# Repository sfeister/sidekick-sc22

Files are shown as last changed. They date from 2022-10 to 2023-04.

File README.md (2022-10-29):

# sidekick-sc22

Physical demonstration of closed loop control systems for machine learning. Supercomputing Conference 2022.

Collaborative work between California State University Channel Islands and Lawrence Livermore National Laboratory.

Based directly on the first Sidekick EPICS system we built: https://github.com/sfeister/sidekick-epics

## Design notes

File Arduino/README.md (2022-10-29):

# Arduino

Each Raspberry Pi has exactly one or more Arduinos attached. The Raspberry Pi sends commands and receives data from the Arduino(s) via USB.

Each .ino sketch in this folder is compiled and uploaded to an Arduino Nano or Arduino Uno. Then, the Arduino is plugged into a Raspberry Pi via USB.

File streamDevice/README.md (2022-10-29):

# streamDevice

Each Raspberry Pi has one or more Arduinos attached. The Raspberry Pi sends commands and receives data from the Arduino(s) via USB.

USB serial communication is translated to and from EPICS process variables via an EPICS module called [StreamDevice](
http://epics.web.psi.ch/software/streamdevice/).

"streamDevice" settings files for each EPICS input/output controller (on the Raspberry Pi) are contained in this folder.

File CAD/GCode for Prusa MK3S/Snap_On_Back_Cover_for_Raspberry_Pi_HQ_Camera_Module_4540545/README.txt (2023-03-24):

Snap On Back Cover for Raspberry Pi HQ Camera Module by mikelane76 on Thingiverse: https://www.thingiverse.com/thing:4540545

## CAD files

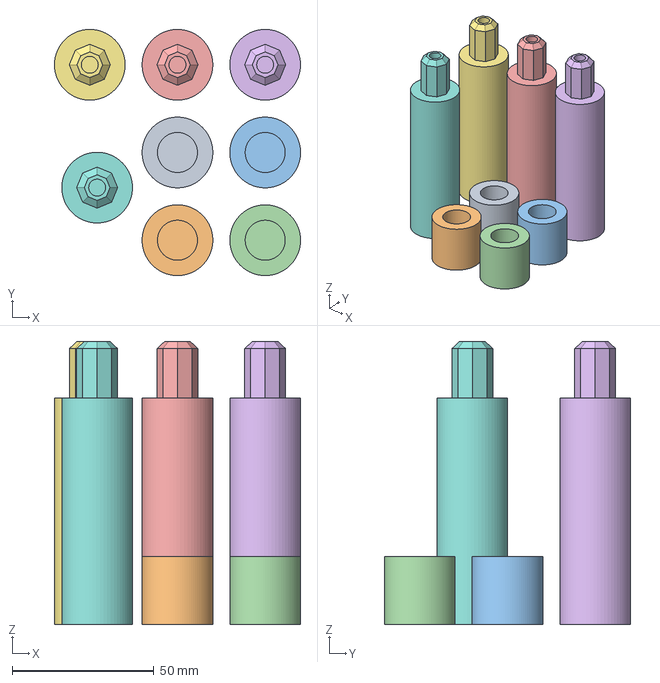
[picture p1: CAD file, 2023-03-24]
CAD/PrusaSlicer/Acrylic Posts and Caps (print in accent color).3mf
87.0 x 87.0 x 100.0 mm
Acrylic Support Post Caps.stl x 4
Acrylic Support Post.stl x 4

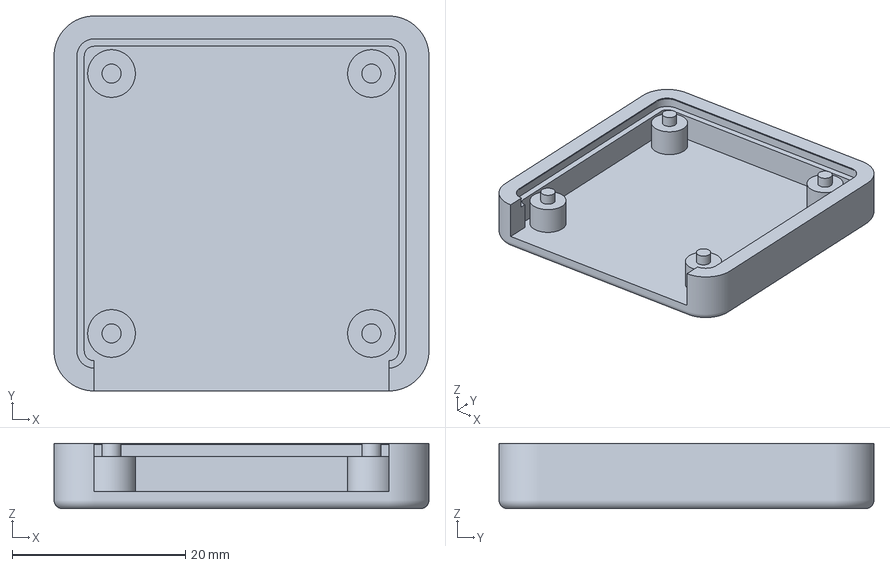
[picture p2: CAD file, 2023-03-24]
CAD/PrusaSlicer/Snap_On_Back_Cover_for_Raspberry_Pi_HQ_Camera_Module_4540545/RPi_HQ_Camera_Back (print in accent color).3mf
43.3 x 43.3 x 7.55 mm

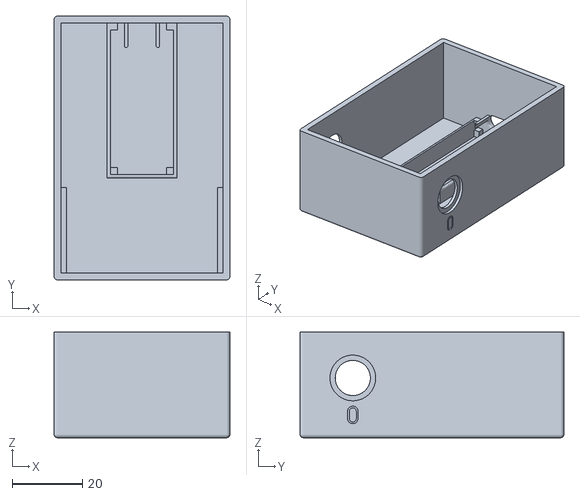
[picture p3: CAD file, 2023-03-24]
CAD/STL/Pulse Generator Enclosure.stl
50.0 x 75.0 x 30.0

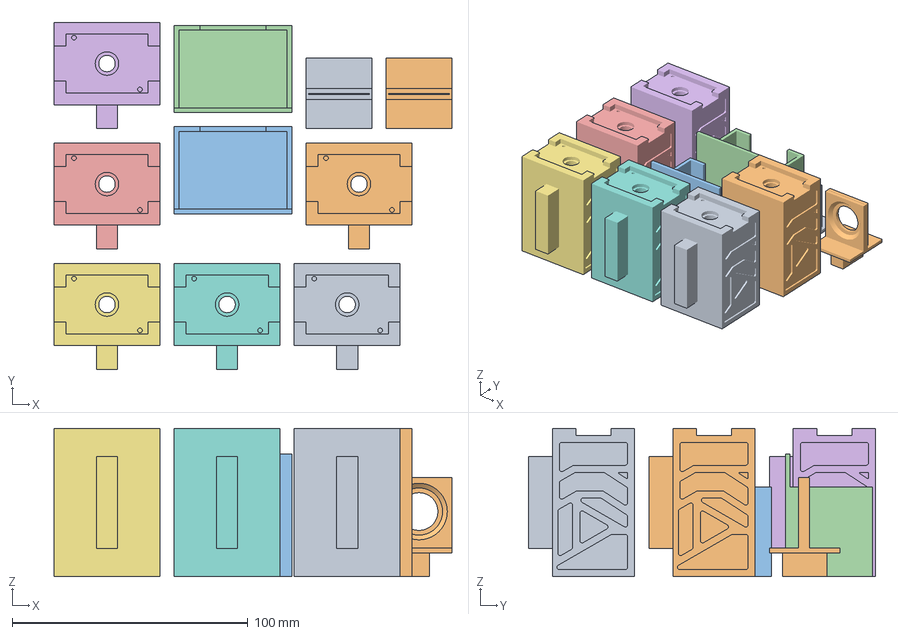
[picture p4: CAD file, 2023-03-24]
CAD/PrusaSlicer/Targets and Hats and Flashing LEDs (print in black).3mf
169.0 x 147.5 x 63.0 mm
Target With Slot for Deli-Paper.stl x 2
Target Hat.stl x 2
Flashing NeoPixel LED Enclosure.stl x 6

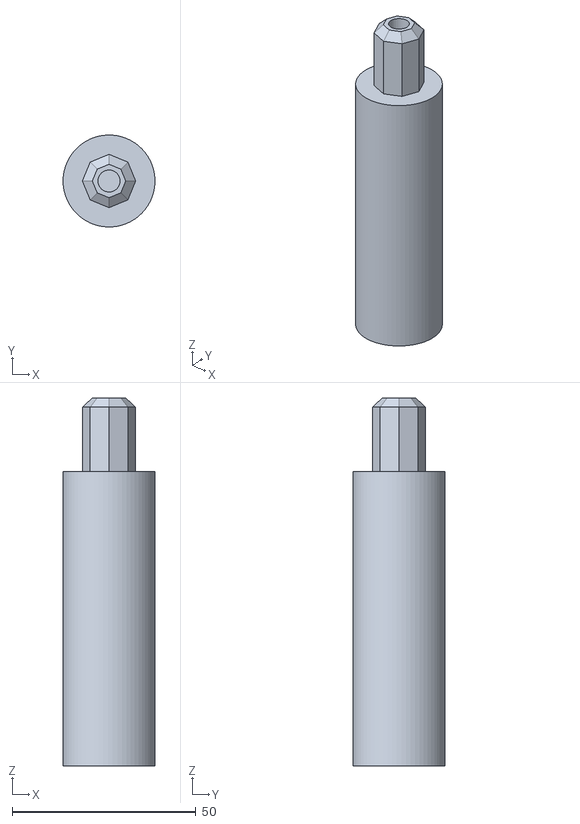
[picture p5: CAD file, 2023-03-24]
CAD/STL/Acrylic Support Post.stl
25.0 x 25.0 x 100.0

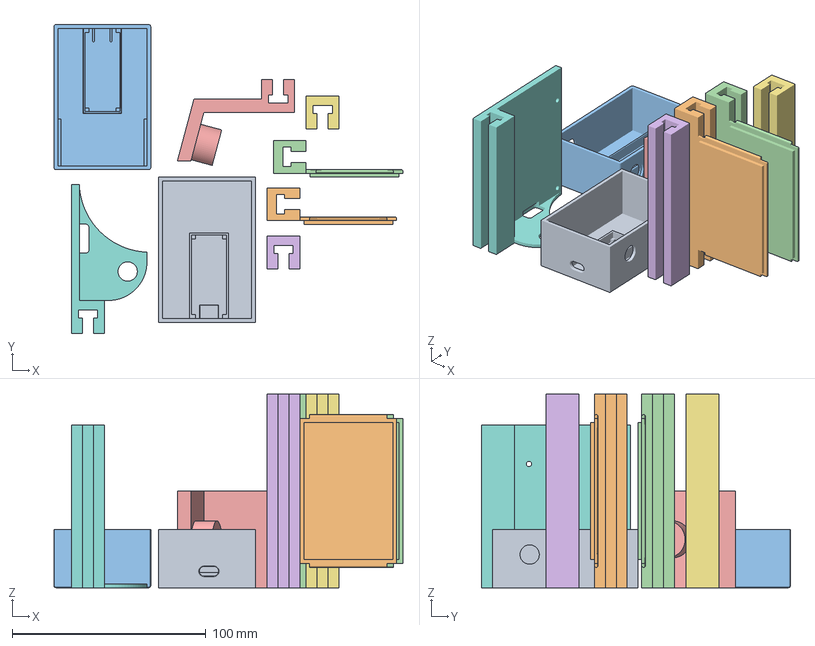
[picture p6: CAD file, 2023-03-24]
CAD/PrusaSlicer/Boxes Lids Clips and Camera Mounts (print in gray).3mf
180.4 x 159.6 x 100.0 mm
Flashing NeoPixel LED Driver Enclosure.stl
Pulse Generator Clip-On Lid.stl x 2
Pulse Generator Enclosure.stl
PiHQ Camera Clip-On Mount.stl
Sidelight LED Strip Clip-On.stl x 2
Raspberry Pi 4 Clip-On Base with BNC.stl

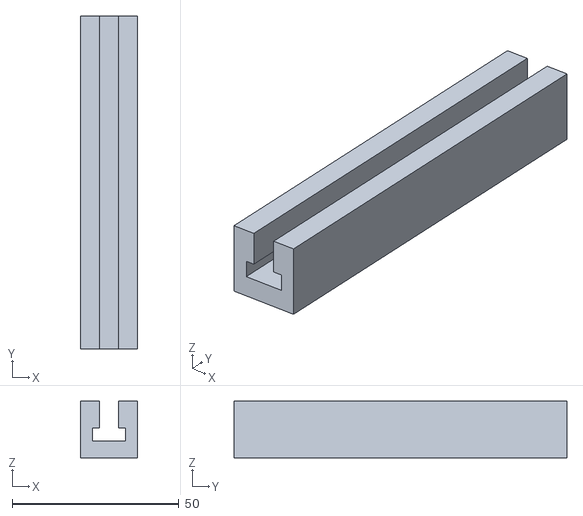
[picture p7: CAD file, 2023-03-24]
CAD/STL/Sidelight LED Strip Clip-On.stl
17.0 x 100.0 x 17.0

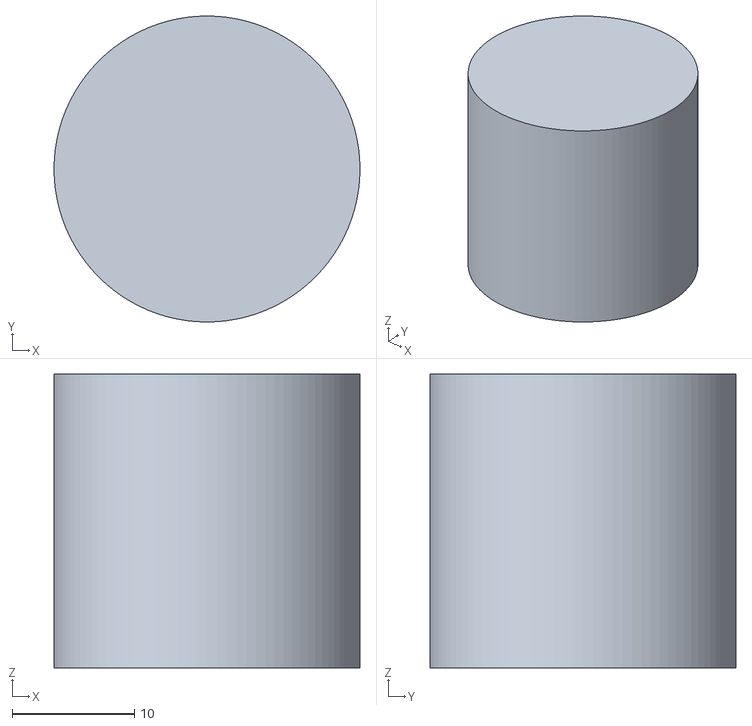
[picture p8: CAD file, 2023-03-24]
CAD/STL/Acrylic Support Post Caps.stl
25.0 x 25.0 x 24.0

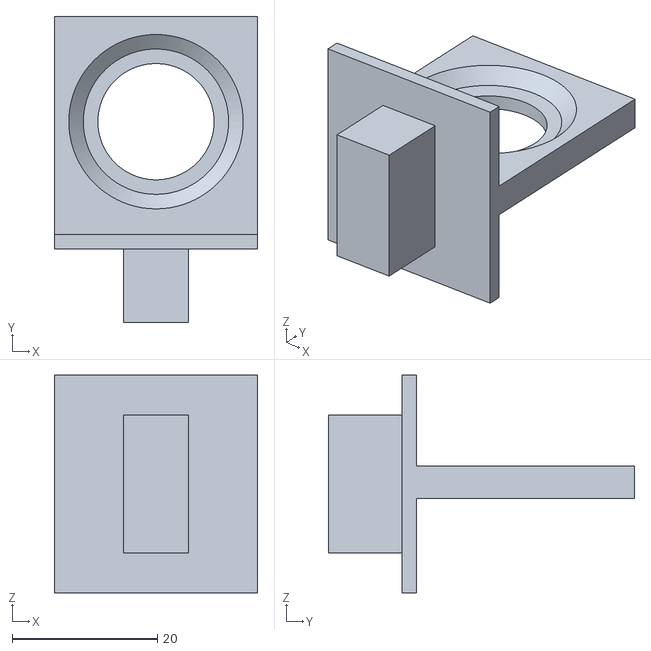
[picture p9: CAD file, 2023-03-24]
CAD/STL/Target With Slot for Deli-Paper.stl
28.0 x 42.2 x 30.0

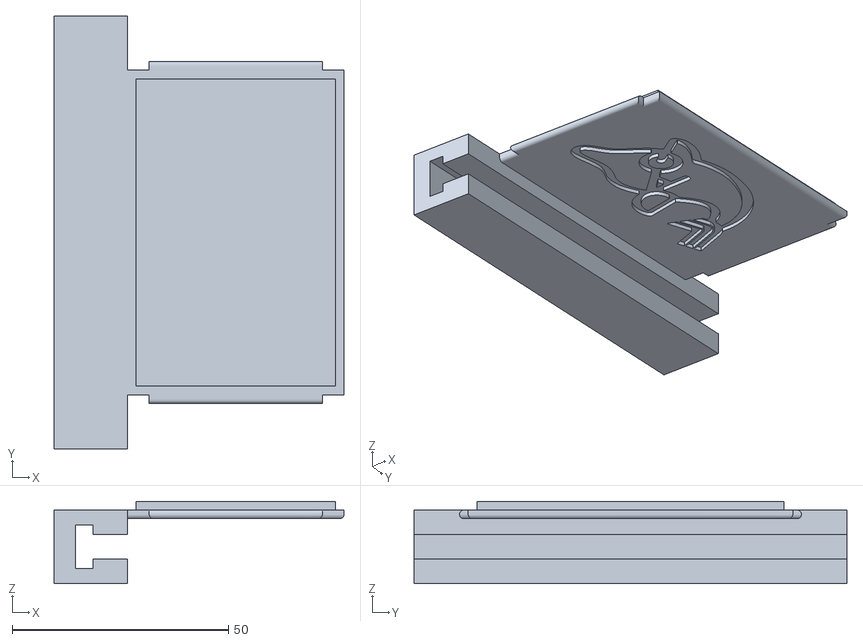
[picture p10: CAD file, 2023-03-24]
CAD/STL/Pulse Generator Clip-On Lid.stl
67.0 x 100.0 x 19.0

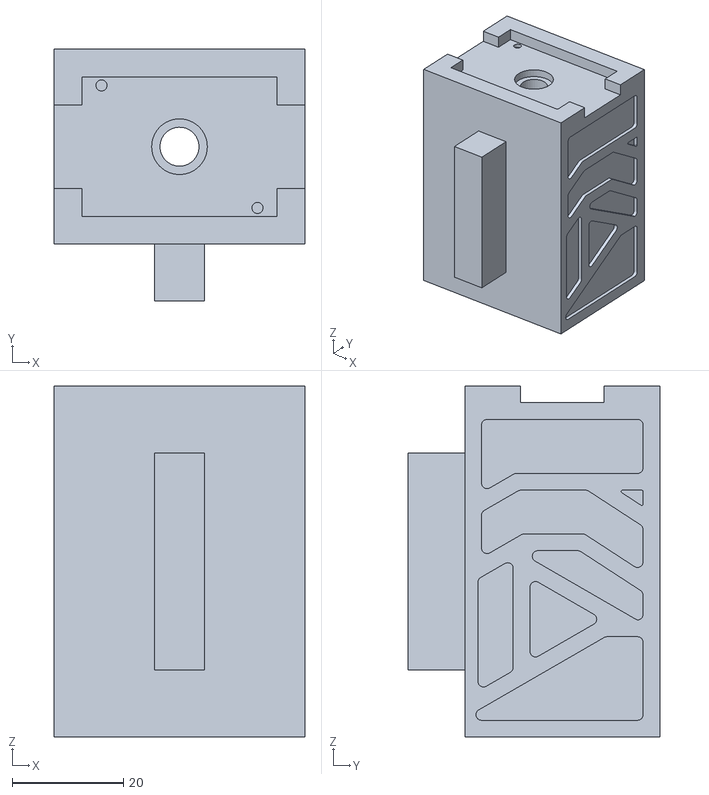
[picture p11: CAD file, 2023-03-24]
CAD/STL/Flashing NeoPixel LED Enclosure.stl
45.0 x 45.2 x 63.0

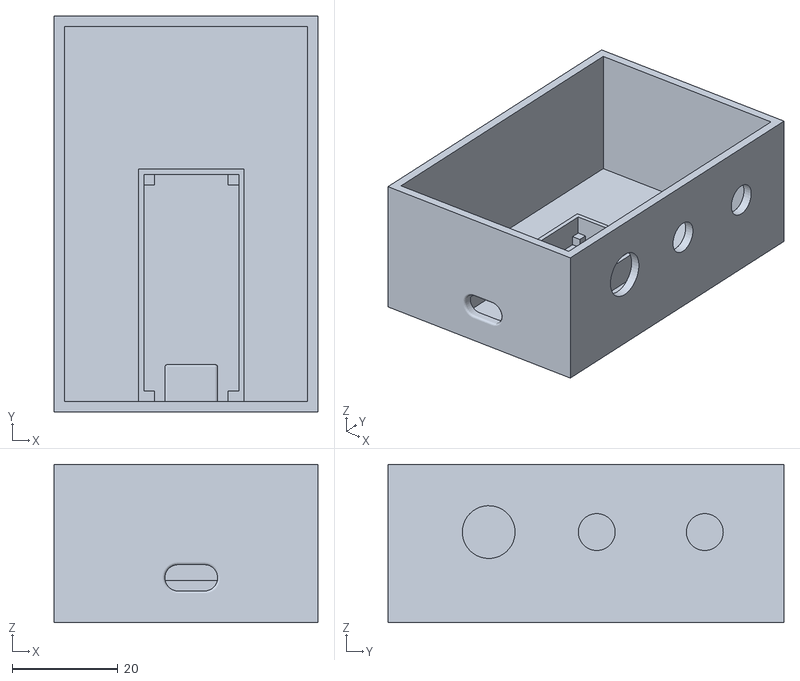
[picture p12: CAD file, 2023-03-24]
CAD/STL/Flashing NeoPixel LED Driver Enclosure.stl
50.0 x 75.0 x 30.0

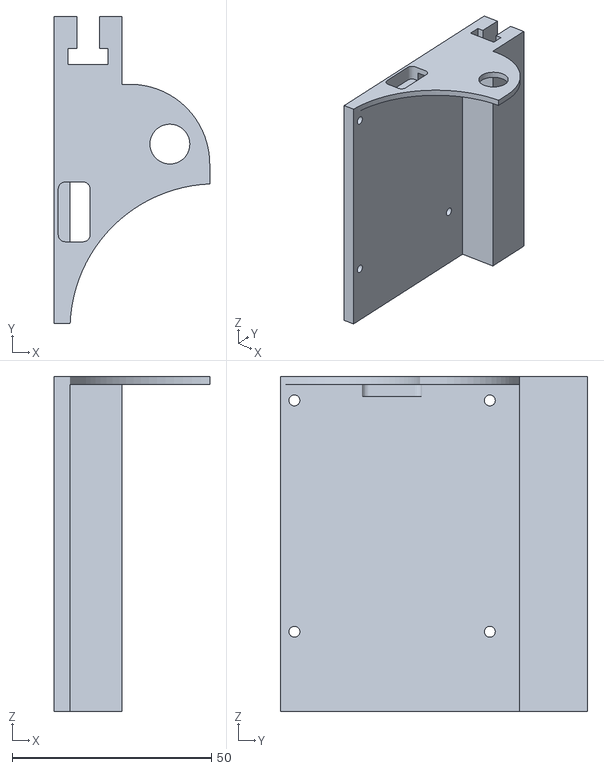
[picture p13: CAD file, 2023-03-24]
CAD/STL/Raspberry Pi 4 Clip-On Base with BNC.stl
39.0 x 77.0 x 84.0

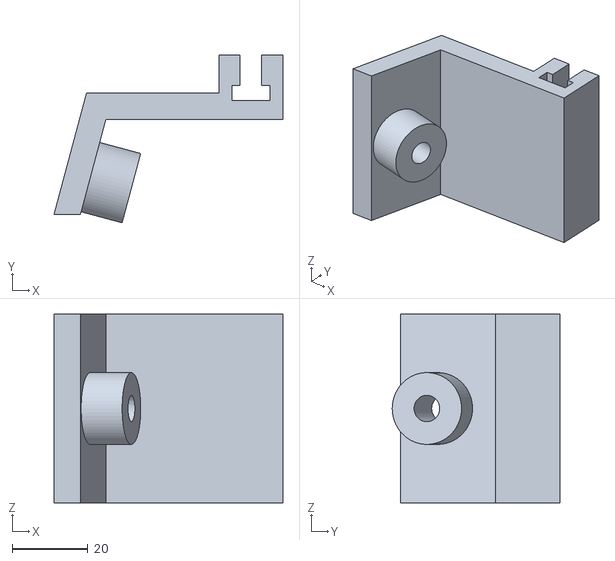
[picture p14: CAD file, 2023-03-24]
CAD/STL/PiHQ Camera Clip-On Mount.stl
60.6 x 44.4 x 50.0

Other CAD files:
CAD/STL/Snap_On_Back_Cover_for_Raspberry_Pi_HQ_Camera_Module_4540545/RPi_HQ_Camera_Back.stl
CAD/STL/Target Hat.stl

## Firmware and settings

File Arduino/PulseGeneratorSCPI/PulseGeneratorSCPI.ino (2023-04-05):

/*
PulseGeneratorSCPI.ino

Generates 3.3 V TTL square pulses at a specified repetition rate.

Important Notes:
 * Creates eight independently delayed TTL pulses. Each channel's delay time is specified in milliseconds relative to TRIGOUT.
 * Each TTL pulse is emitted as HIGH (3.3 V) with a 3 millisecond duration, after which is goes back to its LOW state (0 V).
 * The overall repetition rate of the system can be adjusted up to about 20 Hz (depending on other time delay choices).
 * Typical precision of the requested delay times (on an Arduino Uno) should be a millisecond. Timing jitters around about a millisecond.
 * "Time-zero" trigger output can be monitored on Arduino Pin 3.
 * Up to eight channels (CH0 - CH7) of controlled TTL pulse outputs can be wired to Arduino Pins 4, 5, 6, 7, 8, 9, 10, 11.

Serial Commands (lower-case portions are optional):
  *IDN?                 Responds with a device identification string.
  DELay:CHannelN VAL    Sets Channel N (0-7) output delay to VAL (unsigned long integer, in milliseconds).
  DELay:CHannelN?       Responds with output delay (unsigned long integer, in milliseconds) of Channel N (0-7).
  REPrate VAL           Sets system-wide repetition-rate to VAL (double, in Hz).
  REPrate?              Responds with the system-wide repetition-rate (double, in Hz).

References:
 1. Following timer instructions at: https://github.com/contrem/arduino-timer
 2. Following Vrekrer SCPI Parser examples, e.g. at https://github.com/Vrekrer/Vrekrer_scpi_parser/blob/master/examples/Numeric_suffixes/Numeric_suffixes.ino

Created by Scott Feister, Emiko Ito, and Keily Valdez-Sereno of California State University Channel Islands in Fall 2021. Updated for millisecond delays in March 2023.
*/

#include "Arduino.h"
#include <math.h>
#include <arduino-timer.h>
#include "Vrekrer_scpi_parser.h"

#define TRIGOUT 3 // The "zero delay" TRIGOUT TTL pulse is output on Arduino Pin 3
#define NCHAN 8 // Total number independently delayed output TTL pulse output channels
#define CH0 4 // Channel 0 TTL pulse is output on Arduino Pin 4
#define CH1 5 // Channel 1 TTL pulse is output on Arduino Pin 5
#define CH2 6 // Channel 2 TTL pulse is output on Arduino Pin 6
#define CH3 7 // Channel 3 TTL pulse is output on Arduino Pin 7
#define CH4 8 // Channel 4 TTL pulse is output on Arduino Pin 8
#define CH5 9 // Channel 5 TTL pulse is output on Arduino Pin 9
#define CH6 10 // Channel 5 TTL pulse is output on Arduino Pin 10
#define CH7 11 // Channel 5 TTL pulse is output on Arduino Pin 11

/* Serial communication initialization */
SCPI_Parser my_instrument;

/* Timing initialization */
Timer<10, millis, int> timer1; // TTL pulse timer with 10 task slots, millisecond resolution, and handler argument type int
Timer<1, millis> timer2; // rep-rate timer with 1 task slot, millisecond resolution, and void-type handler

int chanPins[NCHAN]; // Pins for each channel
unsigned long delays[NCHAN]; // Millisecond delay times for each channel

int pulseTime = 3; // TTL pulse duration in milliseconds
double repRate = 1.0; // pulse repetition-rate in Hz
unsigned long t0;

/* Timing functions */
bool TTLStop(int chanPin) {
    // Bring this pulse output back to LOW
    digitalWrite(chanPin, LOW);
    return false; // to repeat the action - false to stop
}

bool TTLStart(int chanPin) {
    // Bring this channel output to HIGH
    digitalWrite(chanPin, HIGH);
    timer1.in(pulseTime, TTLStop, chanPin); // Start a timer to bring this signal back to LOW
    return false; // to repeat the action - false to stop
}

bool trigStart(void *argument){
    if (timer1.size() < 1) { // Only start a new set of triggers if the old set is completed
      t0 = millis() + 2; // Set "time zero" two milliseconds into the future to get everything set up first

      // Schedule the "TRIGOUT" / t0 pulse
      timer1.at(t0, TTLStart, TRIGOUT);
      
      // Schedule the channel pulses
      for(int i = 0; i < NCHAN; ++i)
      {
          timer1.at(t0 + delays[i], TTLStart, chanPins[i]); // Start a timer for this channel
      }
    }
    return true; // repeat at the next interval of the timer
}

void updateRepRate(double repRateHz){
  // Sets the repetition-rate, with value in Hz
  timer2.cancel();
  int repTime = round(1000 / repRateHz);
  timer2.every(repTime, trigStart); // Start a timer for this channel
  repRate = repRateHz; // Update the global variable "repRate"
}

/* Serial communication functions */
void identify(SCPI_C commands, SCPI_P parameters, Stream& interface) {
  interface.println(F("DolphinDAQ,SC22 PulseGen,#00,20230405"));
}


void getRepRate(SCPI_C commands, SCPI_P parameters, Stream& interface) {
  interface.println(repRate);
}

void setRepRate(SCPI_C commands, SCPI_P parameters, Stream& interface) {
  String first_parameter = String(parameters.First());
  updateRepRate(first_parameter.toDouble());
}

void getDelay(SCPI_C commands, SCPI_P parameters, Stream& interface) {
  // This function is modified from the Vrekrer examples: https://github.com/Vrekrer/Vrekrer_scpi_parser/blob/master/examples/Numeric_suffixes/Numeric_suffixes.ino
  
  //Get the numeric suffix/index (if any) from the commands
  String header = String(commands.Last());
  header.toUpperCase();
  int suffix = -1;
  sscanf(header.c_str(),"%*[CHANNEL]%u", &suffix);

  //If the suffix is valid, print the channel's value to the interface
  if ( (suffix >= 0) && (suffix < NCHAN) ) {
      interface.println(delays[suffix]);
  }
}

void setDelay(SCPI_C commands, SCPI_P parameters, Stream& interface) {
  // This function is modified from the Vrekrer examples: https://github.com/Vrekrer/Vrekrer_scpi_parser/blob/master/examples/Numeric_suffixes/Numeric_suffixes.ino
  
  //Get the numeric suffix/index (if any) from the commands
  String header = String(commands.Last());
  header.toUpperCase();
  int suffix = -1;
  sscanf(header.c_str(),"%*[CHANNEL]%u", &suffix);

  //If the suffix is valid,
  //use the first parameter (if valid) to set the channel delay
  String first_parameter = String(parameters.First());
  if ( (suffix >= 0) && (suffix < NCHAN) ) {
      delays[suffix] = first_parameter.toInt();
  }
}


void setup() {
  /* Serial communication setup */
  my_instrument.RegisterCommand(F("*IDN?"), &identify);
  my_instrument.RegisterCommand(F("REPrate?"), &getRepRate);
  my_instrument.RegisterCommand(F("REPrate"), &setRepRate);
  my_instrument.SetCommandTreeBase(F("DELay:"));
  my_instrument.RegisterCommand(F("CHannel#?"), &getDelay);
  my_instrument.RegisterCommand(F("CHannel#"), &setDelay);

  /* Timing setup */
  pinMode(TRIGOUT, OUTPUT); // Declare the TRIGOUT pin as a digital output
  pinMode(CH0, OUTPUT);
  pinMode(CH1, OUTPUT);
  pinMode(CH2, OUTPUT);
  pinMode(CH3, OUTPUT);  
  pinMode(CH4, OUTPUT);
  pinMode(CH5, OUTPUT);
  pinMode(CH6, OUTPUT);
  pinMode(CH7, OUTPUT);

  // Save pin numbers into the chanPins array
  chanPins[0] = CH0;
  chanPins[1] = CH1;
  chanPins[2] = CH2;
  chanPins[3] = CH3;
  chanPins[4] = CH4;
  chanPins[5] = CH5;
  chanPins[6] = CH6;
  chanPins[7] = CH7;
    
  // Save initial delay times (in milliseconds) into the delays array
  delays[0] = 0;
  delays[1] = 0;
  delays[2] = 0;
  delays[3] = 0;
  delays[4] = 0;
  delays[5] = 0;
  delays[6] = 0;
  delays[7] = 0;

  // Initialize the repetition rate
  updateRepRate(repRate); // Sets the repetition-rate, with value in Hz

  Serial.begin(115200);
}

void loop() {
  timer1.tick();
  timer2.tick();
  my_instrument.ProcessInput(Serial, "\r\n");
}

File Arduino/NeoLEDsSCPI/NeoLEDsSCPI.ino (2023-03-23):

/*
NeoLEDsSCPI.ino

When externally triggered, flashes six LEDs a single time. Each LED has its own flash duration and brightness.

Built directly off of LEDsSCPI.ino from the Sidekick system. Adapted for use with Adafruit Neopixels.

Important Notes:
 * LED flash begins abbout 5 milliseconds after the external trigger is received.
 * External trigger should be wired to Arduino Pin 2.
 * The Neopixel data pin should be wired to Arduino Pin 3.
 
Serial Commands (lower-case portions are optional):
  *IDN?                 Responds with a device identification string.
  DURation:LEDN VAL     Sets LED N (0-5) pulse duration to VAL (unsigned long integer, in milliseconds).
  DURation:LEDN?        Responds with LED N (0-5) pulse duration (unsigned long integer, in milliseconds).
  BRIGhtness:LEDN VAL   Sets LED N (0-5) brightness (PWM duty cycle) to VAL (integer, 0 to 255).
  BRIGhtness:LEDN?      Responds with LED N (0-5) brightness (PWM duty cycle)(integer, 0 to 255).
  RED:LEDN VAL          Sets LED N (0-5) to a Red VAL (0-1)
  RED:LEDN?             Responds with LED N (0-5) Red VAL (0-1)
  GREEN:LEDN VAL        Sets LED N (0-5) to a Green VAL (0-1)
  GREEN:LEDN?           Responds with LED N (0-5) Green VAL (0-1)
  BLUE:LEDN VAL         Sets LED N (0-5) to a Blue VAL (0-1)
  BLUE:LEDN?            Responds with LED N (0-5) Blue VAL (0-1)
 
References:
 1. Following timer instructions at: https://github.com/contrem/arduino-timer
 2. Following Vrekrer SCPI Parser examples, e.g. at https://github.com/Vrekrer/Vrekrer_scpi_parser/blob/master/examples/Numeric_suffixes/Numeric_suffixes.ino
 3. Attaching an interrupt pin for external triggering: https://www.arduino.cc/reference/en/language/functions/external-interrupts/attachinterrupt/ 

Created by Emiko Ito, Keily Valdez-Sereno, and Scott Feister of California State University Channel Islands between 2021 - 2022. Updated for miliseconds in March 2023.
*/

#include "Arduino.h" 
#include <arduino-timer.h>
#include "Vrekrer_scpi_parser.h"
#include <Adafruit_NeoPixel.h>
#ifdef __AVR__
  #include <avr/power.h>
#endif


#define EXTTRIG 2 // Note that this pin must be one of the Arduino pins capable of digital interrupt. See table at https://www.arduino.cc/reference/en/language/functions/external-interrupts/attachinterrupt/

#define NLED 6 // Total number of Neopixels in the strand, each with independent duration and brightness
#define LED0 3  //this is the data pin we will use for the neopixel strand

Adafruit_NeoPixel pixels(NLED, LED0, NEO_RGBW + NEO_KHZ800);


Timer<16, millis, int> timer1; // Timer with 16 task slots, millisecond resolution, and handler argument type int

//int LEDPins[NLED]; // Arduino pin numbers for each of the six LED outputs
int brights[NLED]; // Brightnesses for each of the six LEDs, when on
float red[NLED] =   {1, 0, 0, 1, 0, 0.75}; //red values for each pixel
float green[NLED] = {0, 1, 0, 0, 1, 0.25}; //green values for each pixel
float blue[NLED] =  {0, 0, 1, 1, 1, 0.50}; //blue values for each pixel
unsigned long durations[NLED]; // Pulse duration times, in milliseconds, for each of the six LEDs
unsigned long t0;
int trigCount = 0;

SCPI_Parser my_instrument;
int brightness = 0; // temp variable
float value = 0; // temp variable

/* LED control functions */
bool LEDStart(int LEDid) {
    // Turn on the LED of this index (0-5), with a specified brightness
    pixels.setPixelColor(LEDid, pixels.Color(brights[LEDid] * red[LEDid], brights[LEDid] * green[LEDid], brights[LEDid] * blue[LEDid]));
    pixels.show();
    return false; // to repeat the action - false to stop
}

bool LEDStop(int LEDid) {
    // Turn off the LED of this index (0-5)
    //just sets whatever pixel to all 0s so it's nothing
    pixels.setPixelColor(LEDid, pixels.Color(0, 0, 0, 0)); //set first pixel to color RED
    pixels.show();
    return false; // to repeat the action - false to stop
}

/* Timing functions */

// Interrupt service routine (ISR): Called upon external trigger.
// Starts one-time timers that govern the start/stop pulse of the LEDs
void myISR() {
    // Pulse the LEDs once, each with its own brightness and duration
    trigCount++;
    if (timer1.size() < 1) { // Only start a new set of LED pulses if the old set is completed
      t0 = millis() + 5; // Set "LED pulse time zero" to five milliseconds into the future to get everything set up first

      // Schedule the LED pulse starts and stops
      for(int i = 0; i < (NLED); ++i)
      {
          timer1.at(t0, LEDStart, i); // Set the start time for this LED
          timer1.at(t0 + durations[i], LEDStop, i); // Set the stop time for this LED (must be significantly after the start time)
      }
    }
    String triggerMsg = "STREAM " + String(trigCount) + ",";
    for (int i = 0; i < NLED; i++){
      triggerMsg = (triggerMsg + String(brights[i]) + ",");
    }    
    Serial.println(triggerMsg);
    
}

/* Serial communication functions */
void identify(SCPI_C commands, SCPI_P parameters, Stream& interface) {
  interface.println(F("DolphinDAQ,SC22 Neo-LEDs,#00,20230323"));
}

void getBrightness(SCPI_C commands, SCPI_P parameters, Stream& interface) {
  //Get the numeric suffix/index (if any) from the commands
  String header = String(commands.Last());
  header.toUpperCase();
  int suffix = -1;
  sscanf(header.c_str(),"%*[LED]%u", &suffix);

  //If the suffix is valid, respond with the LED's duration
  if ( (suffix >= 0) && (suffix < NLED) ) {
     interface.println(String(brights[suffix], DEC));
  }
}

void setBrightness(SCPI_C commands, SCPI_P parameters, Stream& interface) { 
  //Get the numeric suffix/index (if any) from the commands
  String header = String(commands.Last());
  header.toUpperCase();
  int suffix = -1;
  sscanf(header.c_str(),"%*[LED]%u", &suffix);

  //If the suffix is valid,
  //use the first parameter (if valid) to set the LED brightness
  if ( (suffix >= 0) && (suffix < NLED) ) {
    if(parameters.Size() > 0) {
      value = String(parameters[0]).toInt();
      brights[suffix] = constrain(value, 0, 255);
      //set brightness value in array, then we're gucci
    }
  }
}

void getDuration(SCPI_C commands, SCPI_P parameters, Stream& interface) {
  //Get the numeric suffix/index (if any) from the commands
  String header = String(commands.Last());
  header.toUpperCase();
  int suffix = -1;
  sscanf(header.c_str(),"%*[LED]%u", &suffix);

  //If the suffix is valid, respond with the LED's duration
  if ( (suffix >= 0) && (suffix < NLED) ) {
     interface.println(durations[suffix]);
  }
}
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

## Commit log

2022-11-09 Added Arduino and commands for all elements, even pulse generator (which was mostly cloned from sidekick system). Upgraded identification responses for clarity to indicate SC22 and the date of the fi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
2022-11-09 Updated Neo-LEDs Arduino for naming of version with date
2022-11-09 Removed channel 5 from LEDs database, since that does not exist
2022-11-12 Working towards an updated python ioc for the camera
2022-11-12 Working Camera IOC at 1Hz, no image feedback yet
2022-11-12 Working camera IOC
2022-11-12 Demos of using camera ioc
2022-11-13 Update NeoLEDsSCPI.ino with RGB controls
    Added RGB SCPI commands and methods.
    Added and commented out a print format for triggers.
2022-11-13 Update NeoLEDsSCPI.ino
    Removed comments around the print statements for each trigger.
2022-11-13 Working main.py for camera, including exposure controls
2022-11-14 Modifying the LEDs and Knobs.
2022-11-14 Updated data methods in leds.db and leds.proto
2022-11-14 Update Arduino LEDs, actually works
2022-11-14 Added delay for camera of 50 microseconds
2022-11-14 Updated camera trigger delay to 100 ms to give plenty of time
2022-11-14 Updated LEDs Arduino, trigger message shortened
    [NeoLEDsSCPI.ino]
2022-11-14 Updated camera
2023-01-26 Updating Pi Camera for proper triggered image preview with ROI showing
2023-03-23 Updated to reflect new naming conventions for arduinos and tty udev rules
2023-03-23 Updating initialization, changed arduinos to milliseconds, allowed last LED to flash
2023-03-24 Added 3D printing files
    [Acrylic Posts and Caps (print in accent color).3mf, Acrylic Support Post Caps.stl, Acrylic Support Post.stl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]
2023-04-05 Fixed documentation on milliseconds vs microseconds
    [PulseGeneratorSCPI.ino]
